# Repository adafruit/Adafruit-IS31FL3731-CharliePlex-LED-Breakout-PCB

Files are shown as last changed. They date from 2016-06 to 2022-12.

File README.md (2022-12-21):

## Adafruit IS31FL3731 CharliePlex LED Breakout PCB
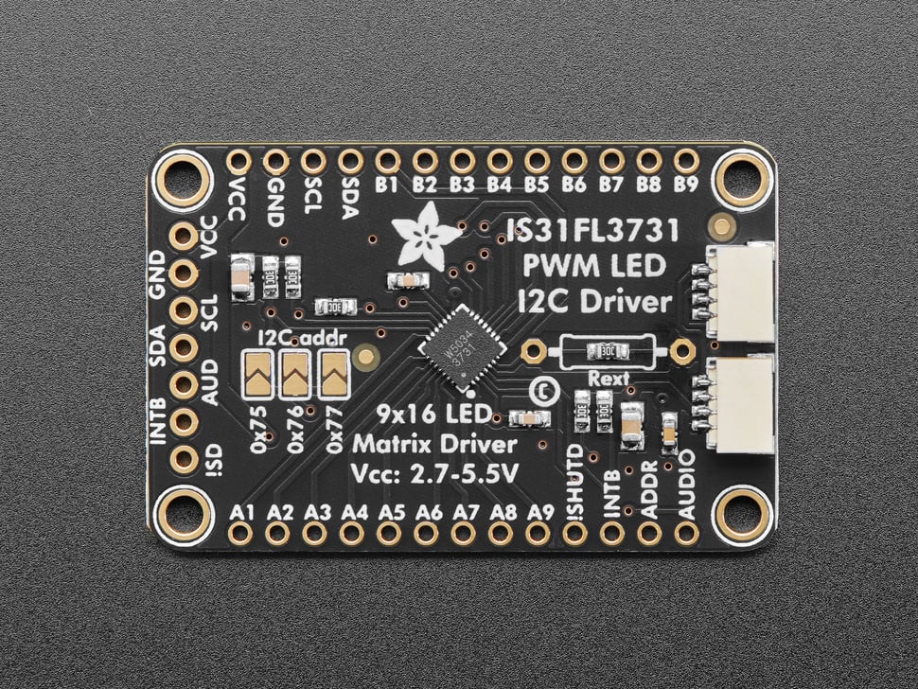
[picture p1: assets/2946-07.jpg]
<a href="http://www.adafruit.com/products/2946"><br/>
Click here to purchase one from the Adafruit shop</a>

The IS31FL3731 will let you get back to that classic LED matrix look, with a nice upgrade! This I2C LED driver chip has the ability to PWM each individual LED in a 16x9 grid so you can have beautiful LED lighting effects, without a lot of pin twiddling. Simply tell the chip which LED on the grid you want lit, and what brightness and it's all taken care of for you.

The IS31FL3731 is a nice little chip - it can use 2.7-5.5V power and logic so its flexible for use with any microcontroller. You can set the address so up to 4 matrices can share an I2C bus. Inside is enough RAM for 8 seperate frames of display memory so you can set up multiple frames of an animation and flip them to be displayed with a single command.

This chip is great for making small LED displays, and we even designed the breakout to match up with our ready-to-go LED grids in red, yellow, green, blue and white. Sandwich the driver and matrix breakout, solder together for a compact setup. Or you can DIY your own setup, just follow the LED grid schematic in the IS31FL3731 datasheet.

To get you going fast, we spun up a custom-made PCB in the STEMMA QT form factor, making it easy to interface with. The STEMMA QT connectors on either side are compatible with the SparkFun Qwiic I2C connectors. This allows you to make solderless connections between your development board and the IS31FL3731 or to chain it with a wide range of other sensors and accessories using a compatible cable. The IS31 is compatible with 3-5V power and logic, so it's ready to go with just about any microcontroller or microcomputer board!

Please note this does not come with any LEDs, you can pick up a matching LED matrix from us or DIY your own.

Pick up a driver board and your favorite color LEDs to match. You'll need to do some basic soldering to attach the driver backpack and matrix together, and run wires to your microcontroller, but its not too hard. Then install our Arduino or CircuitPython libraries to get some LEDs blinking immediately. Our library is Adafruit_GFX compatible so you can draw lines, circles, text, and small bitmaps if you want more graphics control

Check out our detailed tutorial for Arduino & CircuitPython support, pinouts, assembly, wiring, and more!

See the following products for various flavors of this product:

- https://www.adafruit.com/products/2946 (the IS31FL breakout)
- https://www.adafruit.com/products/2973 (blue LEDs)
- https://www.adafruit.com/products/2974 (cool white LEDs)
- https://www.adafruit.com/products/2948 (yellow LEDs)
- https://www.adafruit.com/products/2947 (red LEDs)
- https://www.adafruit.com/products/2972 (green LEDs)

PCB files for the IS31FL3731 CharliePlex LED Breakouts. The format is EagleCAD schematic and board layout

### License

Adafruit invests time and resources providing this open source design, please support Adafruit and open-source hardware by purchasing products from [Adafruit](https://www.adafruit.com)!

All text above must be included in any redistribution

Designed by Limor Fried/Ladyada for Adafruit Industries.
Creative Commons Attribution/Share-Alike, all text above must be included in any redistribution. 
See license.txt for additional information.

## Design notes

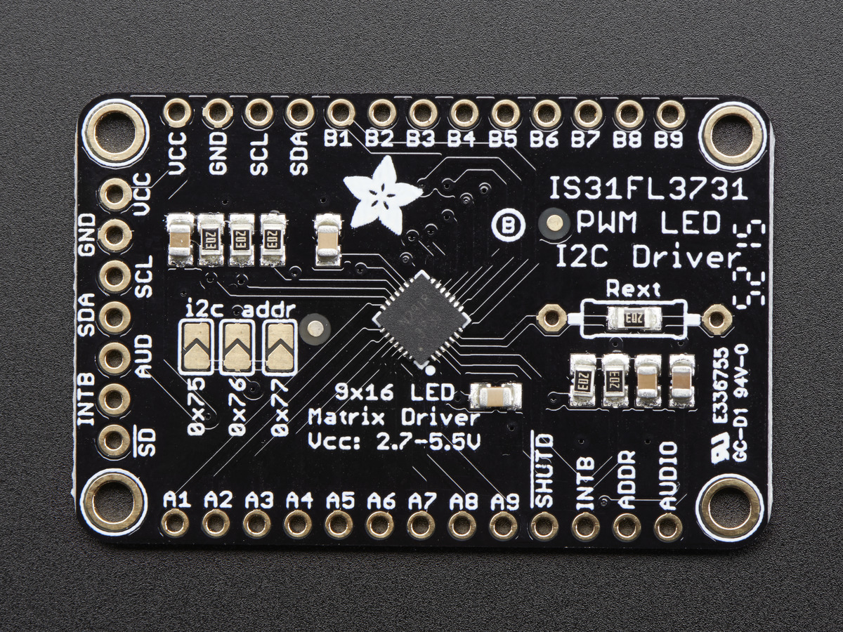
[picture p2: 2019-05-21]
assets/image.jpg

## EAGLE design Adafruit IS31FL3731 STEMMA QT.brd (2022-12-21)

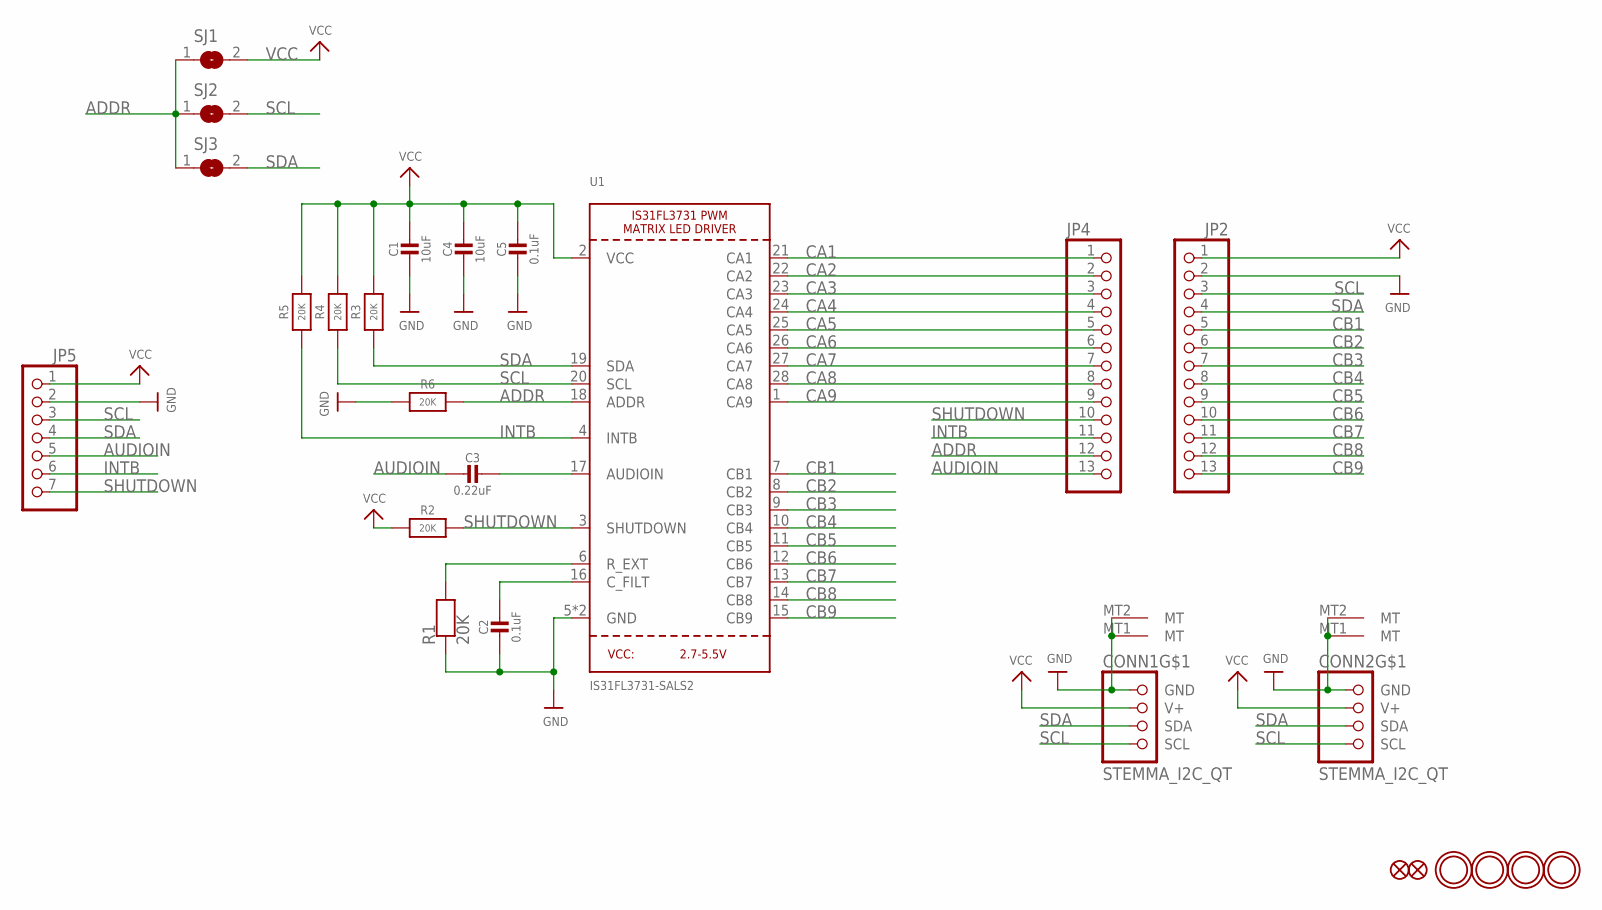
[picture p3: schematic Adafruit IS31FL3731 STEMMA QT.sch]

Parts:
C1, C4: 10uF; 0805-NO
C2, C5: 0.1uF; 0603-NO
C3: 0.22uF; 0603-NO
CONN1, CONN2: STEMMA_I2C_QT; JST_SH4
FID1, FID2: FIDUCIAL_1MM
JP2, JP4: HEADER-1X13; 1X13_ROUND_70
JP5: HEADER-1X7THICKER; 1X07_ROUND_76
R1: 20K; 0603-THM
R2, R3, R4, R5, R6: 20K; 0603-NO
SJ1, SJ2, SJ3: SOLDERJUMPER; SOLDERJUMPER_ARROW_NOPASTE
U1: IS31FL3731-SALS2; QFN28_4MM_0.4MM
U$3, U$4, U$5, U$6: MOUNTINGHOLE2.5; MOUNTINGHOLE_2.5_PLATED

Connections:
ADDR: JP4.12, R6.2, SJ1.1, SJ2.1, SJ3.1, U1.18 (ADDR)
AUDIOIN: C3.2, JP4.13, JP5.5
CA1: JP4.1, U1.21 (CA1)
CA2: JP4.2, U1.22 (CA2)
CA3: JP4.3, U1.23 (CA3)
CA4: JP4.4, U1.24 (CA4)
CA5: JP4.5, U1.25 (CA5)
CA6: JP4.6, U1.26 (CA6)
CA7: JP4.7, U1.27 (CA7)
CA8: JP4.8, U1.28 (CA8)
CA9: JP4.9, U1.1 (CA9)
CB1: JP2.5, U1.7 (CB1)
CB2: JP2.6, U1.8 (CB2)
CB3: JP2.7, U1.9 (CB3)
CB4: JP2.8, U1.10 (CB4)
CB5: JP2.9, U1.11 (CB5)
CB6: JP2.10, U1.12 (CB6)
CB7: JP2.11, U1.13 (CB7)
CB8: JP2.12, U1.14 (CB8)
CB9: JP2.13, U1.15 (CB9)
GND: C1.2, C2.2, C4.2, C5.2, CONN1.1 (GND), CONN1.MT1 (MT), CONN1.MT2 (MT), CONN2.1 (GND), CONN2.MT1 (MT), CONN2.MT2 (MT), JP2.2, JP5.2, R1.1, R1.11 (1), R6.1, U1.5 (GND), U1.THERMAL (GND)
INTB: JP4.11, JP5.6, R5.1, U1.4 (INTB)
unnamed: C2.1, U1.16 (C_FILT)
unnamed: C3.1, U1.17 (AUDIOIN)
REXT: R1.2, R1.22 (2), U1.6 (R_EXT)
SCL: CONN1.4 (SCL), CONN2.4 (SCL), JP2.3, JP5.3, R4.1, SJ2.2, U1.20 (SCL)
SDA: CONN1.3 (SDA), CONN2.3 (SDA), JP2.4, JP5.4, R3.1, SJ3.2, U1.19 (SDA)
SHUTDOWN: JP4.10, JP5.7, R2.2, U1.3 (SHUTDOWN)
VCC: C1.1, C4.1, C5.1, CONN1.2 (V+), CONN2.2 (V+), JP2.1, JP5.1, R2.1, R3.2, R4.2, R5.2, SJ1.2, U1.2 (VCC)

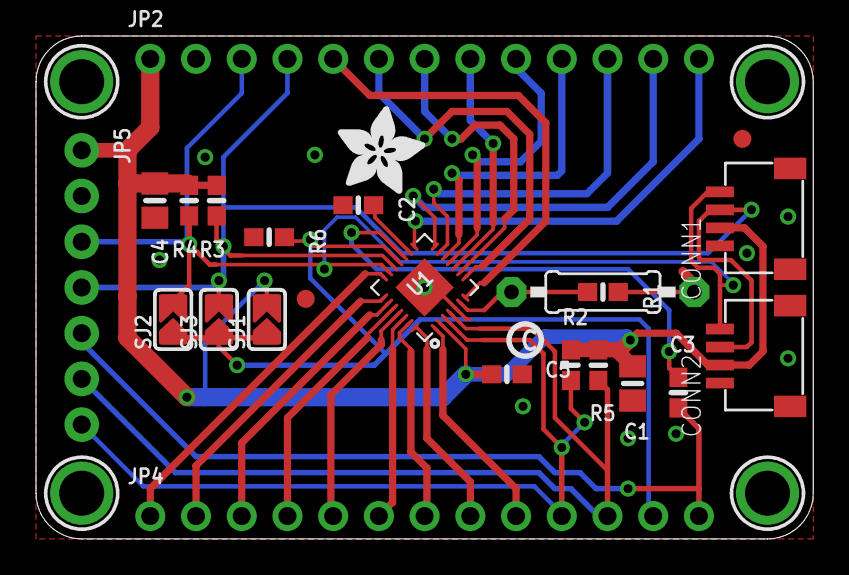
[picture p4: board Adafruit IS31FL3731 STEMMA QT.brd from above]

Board: 2 copper layers, 43.2 x 27.9 mm, 68 parts (0 on the bottom side), 29 nets.

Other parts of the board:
PLABEL0: PLABEL0
PLABEL1: PLABEL1
PLABEL2: PLABEL2
PLABEL3: PLABEL3
PLABEL4: PLABEL4
PLABEL5: PLABEL5
PLABEL6: PLABEL6
PLABEL7: PLABEL7
PLABEL8: PLABEL8
PLABEL9: PLABEL9
PLABEL10: PLABEL10
PLABEL11: PLABEL11
PLABEL12: PLABEL12
PLABEL13: PLABEL13
PLABEL14: PLABEL14
PLABEL15: PLABEL15
PLABEL16: PLABEL16
PLABEL17: PLABEL17
PLABEL18: PLABEL18
PLABEL19: PLABEL19
PLABEL20: PLABEL20
PLABEL21: PLABEL21
PLABEL22: PLABEL22
PLABEL23: PLABEL23
PLABEL24: PLABEL24
PLABEL25: PLABEL25
PLABEL26: PLABEL26
PLABEL27: PLABEL27
PLABEL28: PLABEL28
PLABEL29: PLABEL29
PLABEL30: PLABEL30
PLABEL31: PLABEL31
PLABEL32: PLABEL32
PLABEL33: PLABEL33
PLABEL34: PLABEL34
PLABEL35: PLABEL35
PLABEL36: PLABEL36
PLABEL37: PLABEL37
PLABEL38: PLABEL38
PLABEL39: PLABEL39
U$10: ADAFRUIT_5MM
U$11: PCBFEAT-REV-040

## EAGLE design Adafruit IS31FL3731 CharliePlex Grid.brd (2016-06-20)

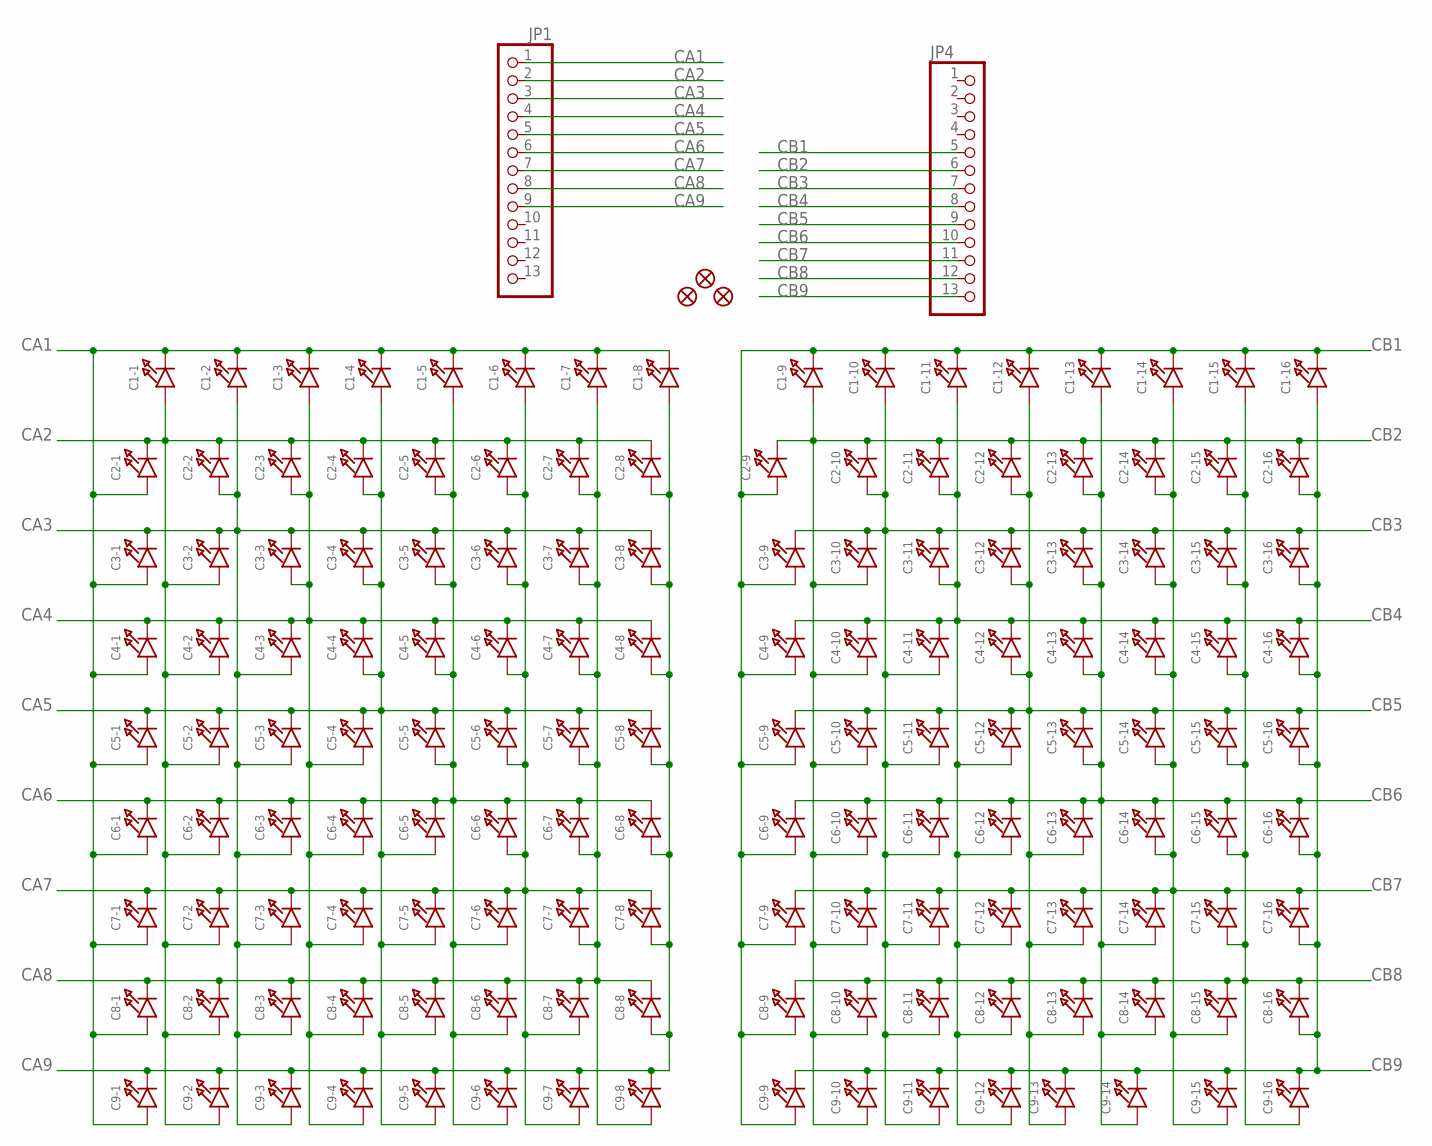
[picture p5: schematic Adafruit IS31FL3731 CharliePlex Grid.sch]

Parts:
C1-1, C1-2, C1-3, C1-4, C1-5, C1-6, C1-7, C1-8, C1-9, C1-10, C1-11, C1-12, C1-13, C1-14, C1-15, C1-16, C2-1, C2-2, C2-3, C2-4, C2-5, C2-6, C2-7, C2-8, C2-9, C2-10, C2-11, C2-12, C2-13, C2-14, C2-15, C2-16, C3-1, C3-2, C3-3, C3-4, C3-5, C3-6, C3-7, C3-8, C3-9, C3-10, C3-11, C3-12, C3-13, C3-14, C3-15, C3-16, C4-1, C4-2, C4-3, C4-4, C4-5, C4-6, C4-7, C4-8, C4-9, C4-10, C4-11, C4-12, C4-13, C4-14, C4-15, C4-16, C5-1, C5-2, C5-3, C5-4, C5-5, C5-6, C5-7, C5-8, C5-9, C5-10, C5-11, C5-12, C5-13, C5-14, C5-15, C5-16, C6-1, C6-2, C6-3, C6-4, C6-5, C6-6, C6-7, C6-8, C6-9, C6-10, C6-11, C6-12, C6-13, C6-14, C6-15, C6-16, C7-1, C7-2, C7-3, C7-4, C7-5, C7-6, C7-7, C7-8, C7-9, C7-10, C7-11, C7-12, C7-13, C7-14, C7-15, C7-16, C8-1, C8-2, C8-3, C8-4, C8-5, C8-6, C8-7, C8-8, C8-9, C8-10, C8-11, C8-12, C8-13, C8-14, C8-15, C8-16, C9-1, C9-2, C9-3, C9-4, C9-5, C9-6, C9-7, C9-8, C9-9, C9-10, C9-11, C9-12, C9-13, C9-14, C9-15, C9-16: LED0603_NOOUTLINE; CHIPLED_0603_NOOUTLINE
FID1, FID2, FID3: FIDUCIAL""; FIDUCIAL_1MM
JP1, JP4: HEADER-1X13; 1X13_ROUND_70

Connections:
CA1: C1-1.C, C1-2.C, C1-3.C, C1-4.C, C1-5.C, C1-6.C, C1-7.C, C1-8.C, C2-1.A, C3-1.A, C4-1.A, C5-1.A, C6-1.A, C7-1.A, C8-1.A, C9-1.A, JP1.1
CA2: C1-1.A, C2-1.C, C2-2.C, C2-3.C, C2-4.C, C2-5.C, C2-6.C, C2-7.C, C2-8.C, C3-2.A, C4-2.A, C5-2.A, C6-2.A, C7-2.A, C8-2.A, C9-2.A, JP1.2
CA3: C1-2.A, C2-2.A, C3-1.C, C3-2.C, C3-3.C, C3-4.C, C3-5.C, C3-6.C, C3-7.C, C3-8.C, C4-3.A, C5-3.A, C6-3.A, C7-3.A, C8-3.A, C9-3.A, JP1.3
CA4: C1-3.A, C2-3.A, C3-3.A, C4-1.C, C4-2.C, C4-3.C, C4-4.C, C4-5.C, C4-6.C, C4-7.C, C4-8.C, C5-4.A, C6-4.A, C7-4.A, C8-4.A, C9-4.A, JP1.4
CA5: C1-4.A, C2-4.A, C3-4.A, C4-4.A, C5-1.C, C5-2.C, C5-3.C, C5-4.C, C5-5.C, C5-6.C, C5-7.C, C5-8.C, C6-5.A, C7-5.A, C8-5.A, C9-5.A, JP1.5
CA6: C1-5.A, C2-5.A, C3-5.A, C4-5.A, C5-5.A, C6-1.C, C6-2.C, C6-3.C, C6-4.C, C6-5.C, C6-6.C, C6-7.C, C6-8.C, C7-6.A, C8-6.A, C9-6.A, JP1.6
CA7: C1-6.A, C2-6.A, C3-6.A, C4-6.A, C5-6.A, C6-6.A, C7-1.C, C7-2.C, C7-3.C, C7-4.C, C7-5.C, C7-6.C, C7-7.C, C7-8.C, C8-7.A, C9-7.A, JP1.7
CA8: C1-7.A, C2-7.A, C3-7.A, C4-7.A, C5-7.A, C6-7.A, C7-7.A, C8-1.C, C8-2.C, C8-3.C, C8-4.C, C8-5.C, C8-6.C, C8-7.C, C8-8.C, C9-8.A, JP1.8
CA9: C1-8.A, C2-8.A, C3-8.A, C4-8.A, C5-8.A, C6-8.A, C7-8.A, C8-8.A, C9-1.C, C9-2.C, C9-3.C, C9-4.C, C9-5.C, C9-6.C, C9-7.C, C9-8.C, JP1.9
CB1: C1-9.C, C1-10.C, C1-11.C, C1-12.C, C1-13.C, C1-14.C, C1-15.C, C1-16.C, C2-9.A, C3-9.A, C4-9.A, C5-9.A, C6-9.A, C7-9.A, C8-9.A, C9-9.A, JP4.5
CB2: C1-9.A, C2-9.C, C2-10.C, C2-11.C, C2-12.C, C2-13.C, C2-14.C, C2-15.C, C2-16.C, C3-10.A, C4-10.A, C5-10.A, C6-10.A, C7-10.A, C8-10.A, C9-10.A, JP4.6
CB3: C1-10.A, C2-10.A, C3-9.C, C3-10.C, C3-11.C, C3-12.C, C3-13.C, C3-14.C, C3-15.C, C3-16.C, C4-11.A, C5-11.A, C6-11.A, C7-11.A, C8-11.A, C9-11.A, JP4.7
CB4: C1-11.A, C2-11.A, C3-11.A, C4-9.C, C4-10.C, C4-11.C, C4-12.C, C4-13.C, C4-14.C, C4-15.C, C4-16.C, C5-12.A, C6-12.A, C7-12.A, C8-12.A, C9-12.A, JP4.8
CB5: C1-12.A, C2-12.A, C3-12.A, C4-12.A, C5-9.C, C5-10.C, C5-11.C, C5-12.C, C5-13.C, C5-14.C, C5-15.C, C5-16.C, C6-13.A, C7-13.A, C8-13.A, C9-13.A, JP4.9
CB6: C1-13.A, C2-13.A, C3-13.A, C4-13.A, C5-13.A, C6-9.C, C6-10.C, C6-11.C, C6-12.C, C6-13.C, C6-14.C, C6-15.C, C6-16.C, C7-14.A, C8-14.A, C9-14.A, JP4.10
CB7: C1-14.A, C2-14.A, C3-14.A, C4-14.A, C5-14.A, C6-14.A, C7-9.C, C7-10.C, C7-11.C, C7-12.C, C7-13.C, C7-14.C, C7-15.C, C7-16.C, C8-15.A, C9-15.A, JP4.11
CB8: C1-15.A, C2-15.A, C3-15.A, C4-15.A, C5-15.A, C6-15.A, C7-15.A, C8-9.C, C8-10.C, C8-11.C, C8-12.C, C8-13.C, C8-14.C, C8-15.C, C8-16.C, C9-16.A, JP4.12
CB9: C1-16.A, C2-16.A, C3-16.A, C4-16.A, C5-16.A, C6-16.A, C7-16.A, C8-16.A, C9-9.C, C9-10.C, C9-11.C, C9-12.C, C9-13.C, C9-14.C, C9-15.C, C9-16.C, JP4.13

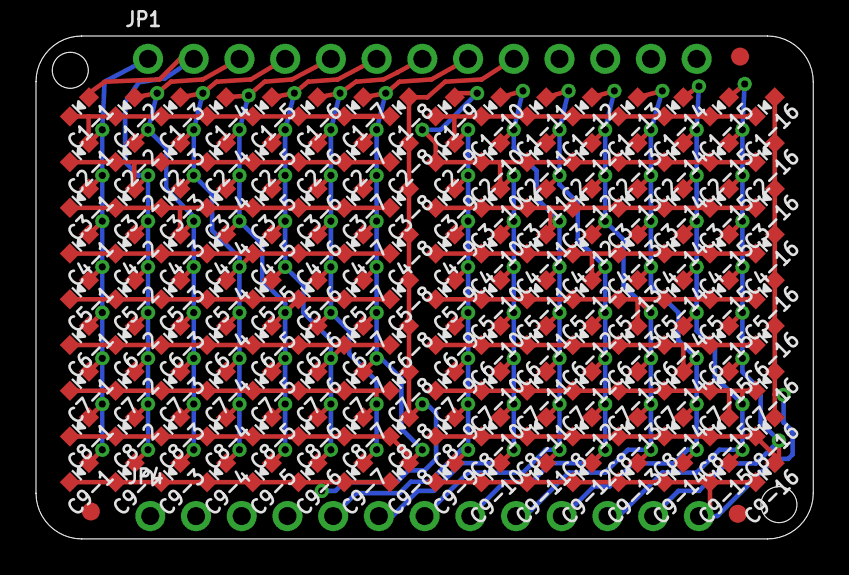
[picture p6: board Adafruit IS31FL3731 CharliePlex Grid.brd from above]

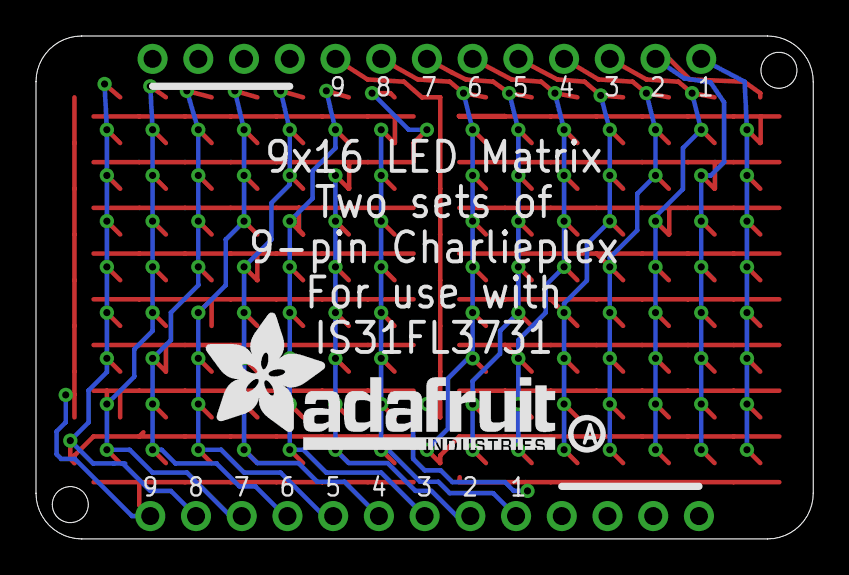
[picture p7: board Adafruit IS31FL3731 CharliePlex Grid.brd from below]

Board: 2 copper layers, 43.2 x 27.9 mm, 151 parts (2 on the bottom side), 18 nets.

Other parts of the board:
U$1: PCBFEAT-REV-040
U$2: ADAFRUIT_TEXT_20MM

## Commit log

2022-12-21 Adding STEMMA QT files
    [Adafruit IS31FL3731 STEMMA QT.brd, Adafruit IS31FL3731 STEMMA QT.sch]
2022-12-21 Updating measures
    [Adafruit IS31FL3731 STEMMA QT.brd]

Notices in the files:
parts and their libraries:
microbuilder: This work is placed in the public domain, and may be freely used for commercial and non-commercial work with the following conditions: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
